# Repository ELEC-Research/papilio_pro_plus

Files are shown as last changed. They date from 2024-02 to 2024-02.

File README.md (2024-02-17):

# Papilio Pro Plus

This is a KICAD implementation of the Papilio Pro including production files for JLCPCB.  The Papilio pro is no longer in production so you can use this to order one for yourself.

There are some changes:
* Built-in USB-C JTAG port

## Author

Phill Brown is the primary author. 

## Licence

This work is licenced under a creative commons licence, rather like the original papilio pro.

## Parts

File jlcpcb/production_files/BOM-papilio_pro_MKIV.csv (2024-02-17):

Comment | Designator | Footprint | LCSC
4k7 | R12 | R_0402_1005Metric | C105870
600 ohm | FB1 | L_0805_2012Metric | C111240
6K8 1% | R3 | R_0603_1608Metric | C114632
10k | R11 | R_0402_1005Metric | C11616
1K8 | R5 | R_0402_1005Metric | C137909
.1uF | C1,C10,C11,C12,C13,C14,C15,C16,C17,C18,C19,C2,C20,C21,C22,C23,C24,C26,C27,C28,C3,C33,C34,C36,C39,C4,C41,C42,C43,C44,C46,C47,C48,C5,C6,C7,C8,C9 | C_0402_1005Metric | C1525
27p | C37,C40 | C_0402_1005Metric | C1557
10u/10V | C25,C29,C30,C31,C32 | C_0805_2012Metric | C15850
USB_C_Receptacle_USB2.0 | J2 | USB_C_Receptacle_HRO_TYPE-C-31-M-12 | C165948
3.3 | C35,C38,C45 | C_0805_2012Metric | C1779
SD103AWS | D3 | D_SOD-323 | C191023
REBOOT | SW1 | SW_SPST_PTS645 | C221872
1.5K 1% | R1,R2,R4 | R_0603_1608Metric | C22843
390 | R6 | R_0402_1005Metric | C25109
470 | R14,R15,R16 | R_0402_1005Metric | C25117
47K | R7 | R_0402_1005Metric | C25563
10k | R17 | R_0402_1005Metric | C25744
12k | R13 | R_0402_1005Metric | C25752
2.2k | R10 | R_0805_2012Metric | C25879
5.1k | R8,R9 | R_0402_1005Metric | C25905
XC6SLX9-TQG144 | U3 | LQFP-144_20x20mm_P0.5mm | C27408
FT2232HL | U7 | LQFP-64_10x10mm_P0.5mm | C27882
3.2X2.5 32MHz Osc | X1 | Oscillator_SMD_Abracon_ASE-4Pin_3.2x2.5mm | C2901581
MT48LC16M16A2P | U5 | TSOP-II-54_22.2x10.16mm_P0.8mm | C41881
93LCxxB | U6 | SO-8_3.9x4.9mm_P1.27mm | C6164
LTC3419MS | U2 | MSOP-10_3x3mm_P0.5mm | C684754
3.3uH | L1,L2 | L_Taiyo-Yuden_MD-5050 | C703751
PWR | D1,D2 | LED_0603_1608Metric | C72043
25CSM04xxSN | U4 | SOIC-8W_5.3x5.3mm_P1.27mm | C82344
~PWREN | D4,D5,D6 | LED_0805_2012Metric | C84256
12MHz | Y1 | Crystal_SMD_3225-4Pin_3.2x2.5mm | C9002

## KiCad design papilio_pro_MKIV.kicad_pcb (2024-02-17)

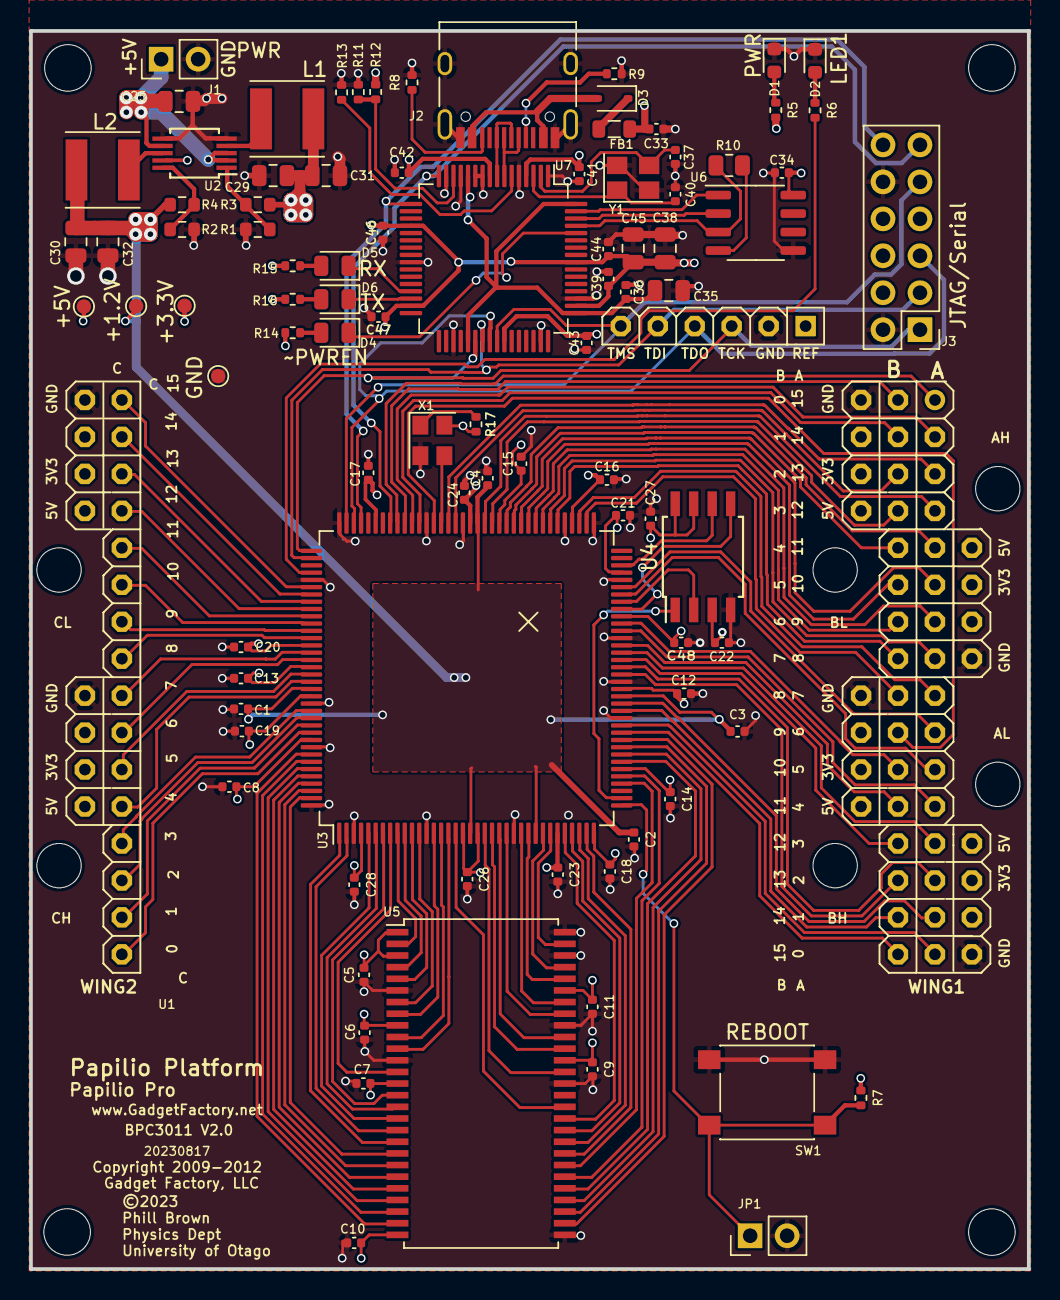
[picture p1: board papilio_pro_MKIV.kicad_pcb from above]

Board: 4 copper layers, 68.6 x 85.1 mm, 96 parts (0 on the bottom side), 132 nets.

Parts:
C1, C2, C3, C4, C5, C6, C7, C8, C9, C10, C11, C12, C13, C14, C15, C16, C17, C18, C19, C20, C21, C22, C23, C24, C26, C27, C28, C48: .1uF; C_0402_1005Metric
C25: 10u/10V; C_0805_2012Metric
C29, C30, C31, C32: 10u/6V3; C_0805_2012Metric
C33, C34, C36, C39, C41, C42, C43, C44, C46, C47: 0.1; C_0402_1005Metric
C35: 3.3; C_0805_2012Metric
C37, C40: 27p; C_0402_1005Metric
C38, C45: 4.7; C_0805_2012Metric
D1: PWR; LED_0603_1608Metric
D2: LED1; LED_0603_1608Metric
D3: SD103AWS; D_SOD-323
D4: ~PWREN; LED_0805_2012Metric
D5: RX; LED_0805_2012Metric
D6: TX; LED_0805_2012Metric
FB1: 600 ohm; L_0805_2012Metric
H1, H2, H3, H4: MountingHole; MountingHole_3.2mm_M3
J1: PWR; PinHeader_1x02_P2.54mm_Vertical
J2: USB_C_Receptacle_USB2.0; USB_C_Receptacle_HRO_TYPE-C-31-M-12
J3: JTAG/Serial; PinHeader_2x06_P2.54mm_Vertical
JP1: JP1E; PinHeader_1x02_P2.54mm_Vertical
L1, L2: 3.3uH; L_Taiyo-Yuden_MD-5050
R1, R2, R4: 1.5K 1%; R_0603_1608Metric
R3: 6K8 1%; R_0603_1608Metric
R5: 1K8; R_0402_1005Metric
R6: 390; R_0402_1005Metric
R7: 47K; R_0402_1005Metric
R8, R9: 5.1k; R_0402_1005Metric
R10: 2.2k; R_0805_2012Metric
R11, R17: 10k; R_0402_1005Metric
R12: 4k7; R_0402_1005Metric
R13: 12k; R_0402_1005Metric
R14, R15, R16: 470; R_0402_1005Metric
SW1: REBOOT; SW_SPST_PTS645
TP1: +3.3V; TestPoint_Pad_D1.0mm
TP2: +1.2V; TestPoint_Pad_D1.0mm
TP3: +5V; TestPoint_Pad_D1.0mm
TP4: GND; TestPoint_Pad_D1.0mm
U1: Papilio Pro; COCOON_48BIT
U2: LTC3419MS; MSOP-10_3x3mm_P0.5mm
U3: XC6SLX9-TQG144; LQFP-144_20x20mm_P0.5mm
U4: 25CSM04xxSN; SOIC-8W_5.3x5.3mm_P1.27mm
U5: MT48LC16M16A2P; TSOP-II-54_22.2x10.16mm_P0.8mm
U6: 93LCxxB; SO-8_3.9x4.9mm_P1.27mm
U7: FT2232HL; LQFP-64_10x10mm_P0.5mm
X1: 3.2X2.5 32MHz Osc; Oscillator_SMD_Abracon_ASE-4Pin_3.2x2.5mm
Y1: 12MHz; Crystal_SMD_3225-4Pin_3.2x2.5mm

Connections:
+1V2: C1.1, C2.1, C3.1, C4.1, C30.1, C32.1, L2.2, R4.2, TP2.1, U3.19 (VCCINT), U3.28 (VCCINT), U3.52 (VCCINT), U3.89 (VCCINT), U3.128 (VCCINT)
+1V8: C35.1, C36.1, U7.12 (VCORE), U7.37 (VCORE), U7.49 (VREGOUT), U7.64 (VCORE)
+3.3V: C5.1, C6.1, C7.1, C8.1, C9.1, C10.1, C11.1, C12.1, C13.1, C14.1, C15.1, C16.1, C17.1, C18.1, C19.1, C20.1, C21.1, C22.1, C23.1, C24.1, C26.1, C27.1, C28.1, C29.1, C31.1, C34.1, C38.1, C39.1, C41.1, C42.1, C43.1, C44.1, C45.1, C46.1, C47.1, C48.1, J3.6, L1.2, R3.2, R7.1, R14.1, R15.1, R16.1, R17.1, TP1.1, U1.3 (3V3), U1.13 (3V3), U1.23 (3V3), U1.33 (3V3), U1.43 (3V3), U1.53 (3V3), U1.J1 (JTAG_REF), U2.9 (RUN2), U3.4 (VCCO_3), U3.18 (VCCO_3), U3.20 (VCCAUX), U3.31 (VCCO_3), U3.36 (VCCAUX), U3.42 (VCCO_2), U3.53 (VCCAUX), U3.63 (VCCO_2), U3.69 (IO_L1N_M0_CMPMISO_2), U3.76 (VCCO_1), U3.86 (VCCO_1), U3.90 (VCCAUX), U3.103 (VCCO_1), U3.122 (VCCO_0), U3.125 (VCCO_0), U3.129 (VCCAUX), U3.135 (VCCO_0), U4.3 (~WP), U4.7 (~HOLD), U4.8 (V_{CC}), U5.1 (VDD), U5.3 (VDDQ), U5.9 (VDDQ), U5.14 (VDD), U5.27 (VDD), U5.43 (VDDQ), U5.49 (VDDQ), U6.8 (VCC), U7.4 (VPHY), U7.9 (VPLL), U7.20 (VCCIO), U7.31 (VCCIO), U7.42 (VCCIO), U7.50 (VREGIN), U7.56 (VCCIO), X1.4 (Vdd)
+5V: C25.1, C33.1, FB1.1, J1.1, R5.2, R12.1, TP3.1, U1.4 (Vin), U1.14 (Vin), U1.24 (Vin), U1.34 (Vin), U1.44 (Vin), U1.54 (Vin), U2.2 (RUN1), U2.3 (MODE), U2.7 (VIN)
/Connectors/OSC_IN: U3.94 (IO_L40N_GCLK10_1), X1.3 (OUT)
/Connectors/W1_A1: U1.A0, U3.48 (IO_L48P_D7_2)
/Connectors/W1_A2: U1.A1, U3.51 (IO_L31P_GCLK31_D14_2)
/Connectors/W1_A3: U1.A2, U3.56 (IO_L30P_GCLK1_D13_2)
/Connectors/W1_A4: U1.A3, U3.58 (IO_L14P_D11_2)
/Connectors/W1_A5: U1.A4, U3.61 (IO_L12N_D2_MISO3_2)
/Connectors/W1_A6: U1.A5, U3.66 (IO_L2N_CMPMOSI_2)
/Connectors/W1_A7: U1.A6, U3.67 (IO_L2P_CMPCLK_2)
/Connectors/W1_A8: U1.A7, U3.75 (IO_L74P_AWAKE_1)
/Connectors/W1_A9: U1.A8, U3.79 (IO_L47P_1)
/Connectors/W1_A10: U1.A9, U3.81 (IO_L46P_1)
/Connectors/W1_A11: U1.A10, U3.83 (IO_L45P_1)
/Connectors/W1_A12: U1.A11, U3.85 (IO_L43P_GCLK5_1)
/Connectors/W1_A13: U1.A12, U3.88 (IO_L42P_GCLK7_1)
/Connectors/W1_A14: U1.A13, U3.93 (IO_L41P_GCLK9_IRDY1_1)
/Connectors/W1_A15: U1.A14, U3.98 (IO_L34P_1)
/Connectors/W1_A16: U1.A15, U3.100 (IO_L33P_1)
/Connectors/W1_B1: U1.B0, U3.99 (IO_L33N_1)
/Connectors/W1_B2: U1.B1, U3.97 (IO_L34N_1)
/Connectors/W1_B3: U1.B2, U3.92 (IO_L41N_GCLK8_1)
/Connectors/W1_B4: U1.B3, U3.87 (IO_L42N_GCLK6_TRDY1_1)
/Connectors/W1_B5: U1.B4, U3.84 (IO_L43N_GCLK4_1)
/Connectors/W1_B6: U1.B5, U3.82 (IO_L45N_1)
/Connectors/W1_B7: U1.B6, U3.80 (IO_L46N_1)
/Connectors/W1_B8: U1.B7, U3.78 (IO_L47N_1)
/Connectors/W1_B9: U1.B8, U3.74 (IO_L74N_DOUT_BUSY_1)
/Connectors/W1_B10: U1.B9, U3.95 (IO_L40P_GCLK11_1)
/Connectors/W1_B11: U1.B10, U3.62 (IO_L12P_D1_MISO2_2)
/Connectors/W1_B12: U1.B11, U3.59 (IO_L13N_D10_2)
/Connectors/W1_B13: U1.B12, U3.57 (IO_L14N_D12_2)
/Connectors/W1_B14: U1.B13, U3.55 (IO_L30N_GCLK0_USERCCLK_2)
/Connectors/W1_B15: U1.B14, U3.50 (IO_L31N_GCLK30_D15_2)
/Connectors/W1_B16: U1.B15, U3.47 (IO_L48N_RDWR_B_VREF_2)
/Connectors/W2_A1: U1.C15, U3.114 (IO_L65N_SCP2_0)
/Connectors/W2_A2: U1.C14, U3.115 (IO_L65P_SCP3_0)
/Connectors/W2_A3: U1.C13, U3.116 (IO_L64N_SCP4_0)
/Connectors/W2_A4: U1.C12, U3.117 (IO_L64P_SCP5_0)
/Connectors/W2_A5: U1.C11, U3.118 (IO_L63N_SCP6_0)
/Connectors/W2_A6: U1.C10, U3.119 (IO_L63P_SCP7_0)
/Connectors/W2_A7: U1.C9, U3.120 (IO_L62N_VREF_0)
/Connectors/W2_A8: U1.C8, U3.121 (IO_L62P_0)
/Connectors/W2_A9: U1.C7, U3.123 (IO_L37N_GCLK12_0)
/Connectors/W2_A10: U1.C6, U3.124 (IO_L37P_GCLK13_0)
/Connectors/W2_A11: U1.C5, U3.126 (IO_L36N_GCLK14_0)
/Connectors/W2_A12: U1.C4, U3.127 (IO_L36P_GCLK15_0)
/Connectors/W2_A13: U1.C3, U3.131 (IO_L35N_GCLK16_0)
/Connectors/W2_A14: U1.C2, U3.132 (IO_L35P_GCLK17_0)
/Connectors/W2_A15: U1.C1, U3.133 (IO_L34N_GCLK18_0)
/Connectors/W2_A16: U1.C0, U3.134 (IO_L34P_GCLK19_0)
/FPGA/A0: U3.140 (IO_L3P_0), U5.23 (A0)
/FPGA/A1: U3.139 (IO_L3N_0), U5.24 (A1)
/FPGA/A2: U3.138 (IO_L4P_0), U5.25 (A2)
/FPGA/A3: U3.137 (IO_L4N_0), U5.26 (A3)
/FPGA/A4: U3.46 (IO_L49P_D3_2), U5.29 (A4)
/FPGA/A5: U3.45 (IO_L49N_D4_2), U5.30 (A5)
/FPGA/A6: U3.44 (IO_L62P_D5_2), U5.31 (A6)
/FPGA/A7: U3.43 (IO_L62N_D6_2), U5.32 (A7)
/FPGA/A8: U3.41 (IO_L64P_D8_2), U5.33 (A8)
/FPGA/A9: U3.40 (IO_L64N_D9_2), U5.34 (A9)
/FPGA/A10: U3.141 (IO_L2N_0), U5.22 (A10)
/FPGA/A11: U3.35 (IO_L1P_3), U5.35 (A11)
/FPGA/A12: U3.34 (IO_L1N_VREF_3), U5.36 (A12)
/FPGA/BA0: U3.143 (IO_L1N_VREF_0), U5.20 (BA0)
/FPGA/BA1: U3.142 (IO_L2P_0), U5.21 (BA1)
/FPGA/CKE: U3.33 (IO_L2P_3), U5.37 (CKE)
/FPGA/CLK: U3.32 (IO_L2N_3), U5.38 (CLK)
/FPGA/CS: U3.1 (IO_L83N_VREF_3), U5.19 (~CS)
/FPGA/DQ0: U3.9 (IO_L50N_3), U5.2 (DQ0)
/FPGA/DQ1: U3.10 (IO_L50P_3), U5.4 (DQ1)
/FPGA/DQ2: U3.11 (IO_L49N_3), U5.5 (DQ2)
/FPGA/DQ3: U3.12 (IO_L49P_3), U5.7 (DQ3)
/FPGA/DQ4: U3.14 (IO_L44N_GCLK20_3), U5.8 (DQ4)
/FPGA/DQ5: U3.15 (IO_L44P_GCLK21_3), U5.10 (DQ5)
/FPGA/DQ6: U3.16 (IO_L43N_GCLK22_IRDY2_3), U5.11 (DQ6)
/FPGA/DQ7: U3.8 (IO_L51P_3), U5.13 (DQ7)
/FPGA/DQ8: U3.21 (IO_L42N_GCLK24_3), U5.42 (DQ8)
/FPGA/DQ9: U3.22 (IO_L42P_GCLK25_TRDY2_3), U5.44 (DQ9)
/FPGA/DQ10: U3.23 (IO_L41N_GCLK26_3), U5.45 (DQ10)
/FPGA/DQ11: U3.24 (IO_L41P_GCLK27_3), U5.47 (DQ11)
/FPGA/DQ12: U3.26 (IO_L37N_3), U5.48 (DQ12)
/FPGA/DQ13: U3.27 (IO_L37P_3), U5.50 (DQ13)
/FPGA/DQ14: U3.29 (IO_L36N_3), U5.51 (DQ14)
/FPGA/DQ15: U3.30 (IO_L36P_3), U5.53 (DQ15)
/FPGA/DQMH: U3.17 (IO_L43P_GCLK23_3), U5.39 (DQMH)
/FPGA/DQML: U3.7 (IO_L51N_3), U5.15 (DQML)
/FPGA/FLASH_CS: U3.38 (IO_L65N_CSO_B_2), U4.1 (~CS)
/FPGA/FLASH_SCK: U3.70 (IO_L1P_CCLK_2), U4.6 (SCK)
/FPGA/FLASH_SI: U3.64 (IO_L3N_MOSI_CSI_B_MISO0_2), U4.5 (SI)
/FPGA/FLASH_SO: U3.65 (IO_L3P_D0_DIN_MISO_MISO1_2), U4.2 (SO)
/FPGA/FPGA-C/REBOOT: JP1.1, R7.2, SW1.1, U3.37 (PROGRAM_B_2)
/FPGA/~CAS: U3.5 (IO_L52N_3), U5.17 (~CAS)
/FPGA/~RAS: U3.2 (IO_L83P_3), U5.18 (~RAS)
/FPGA/~WE: U3.6 (IO_L52P_3), U5.16 (~WE)
/USB JTAG/RXD2: J3.12, U3.105 (IO_L1P_1), U7.17 (ADBUS1)
/USB JTAG/TCK: J3.1, U1.J3 (JTAG_TCK), U3.109 (TCK), U7.38 (BDBUS0)
/USB JTAG/TDI: J3.3, U1.J5 (JTAG_TDI), U3.110 (TDI), U7.39 (BDBUS1)
/USB JTAG/TDO: J3.5, U1.J4 (JTAG_TDO), U3.106 (TDO), U7.40 (BDBUS2)
/USB JTAG/TMS: J3.9, U1.J6 (JTAG_TMS), U3.107 (TMS), U7.41 (BDBUS3)
/USB JTAG/TXD2: J3.11, U3.101 (IO_L32N_1), U7.16 (ADBUS0)
GND: C1.2, C2.2, C3.2, C4.2, C5.2, C6.2, C7.2, C8.2, C9.2, C10.2, C11.2, C12.2, C13.2, C14.2, C15.2, C16.2, C17.2, C18.2, C19.2, C20.2, C21.2, C22.2, C23.2, C24.2, C25.2, C26.2, C27.2, C28.2, C29.2, C30.2, C31.2, C32.2, C33.2, C34.2, C35.2, C36.2, C37.2, C38.2, C39.2, C40.2, C41.2, C42.2, C43.2, C44.2, C45.2, C46.2, C47.2, C48.2, D1.1 (K), D2.1 (K), J1.2, J2.A1 (GND), J2.A12 (GND), J2.B1 (GND), J2.B12 (GND), J2.S1 (SHIELD), J3.2, J3.10, JP1.2, R1.1, R2.1, R8.2, R9.2, R11.2, R13.2, SW1.2, TP4.1, U1.1 (GND), U1.11 (GND), U1.21 (GND), U1.31 (GND), U1.41 (GND), U1.51 (GND), U1.J2 (JTAG_GND), U2.5 (GND), U2.6 (GND), U3.3 (GND), U3.13 (GND), U3.25 (GND), U3.49 (GND), U3.54 (GND), U3.60 (IO_L13P_M1_2), U3.68 (GND), U3.73 (SUSPEND), U3.77 (GND), U3.91 (GND), U3.96 (GND), U3.108 (GND), U3.113 (GND), U3.130 (GND), U3.136 (GND), U3.144 (IO_L1P_HSWAPEN_0), U4.4 (V_{SS}), U5.6 (VSSQ), U5.12 (VSSQ), U5.28 (VSS), U5.41 (VSS), U5.46 (VSSQ), U5.52 (VSSQ), U5.54 (VSS), U6.5 (GND), U7.1 (GND), U7.5 (GND), U7.10 (AGND), U7.11 (GND), U7.13 (TEST), U7.15 (GND), U7.25 (GND), U7.35 (GND), U7.47 (GND), U7.51 (GND), X1.2 (GND), Y1.2, Y1.4
unnamed: D1.2 (A), R5.1
unnamed: D2.2 (A), R6.1
unnamed: D3.2 (A), J2.A4 (VBUS), J2.A9 (VBUS), J2.B4 (VBUS), J2.B9 (VBUS)
unnamed: D3.1 (K), FB1.2
unnamed: D4.2 (A), R14.2
unnamed: D4.1 (K), U7.60 (~PWREN)
unnamed: D5.2 (A), R15.2
unnamed: D5.1 (K), U7.29 (ACBUS3)
unnamed: D6.2 (A), R16.2
unnamed: D6.1 (K), U7.30 (ACBUS4)
unnamed: J2.A5 (CC1), R9.1
unnamed: J2.B5 (CC2), R8.1
unnamed: L1.1, U2.4 (SW1)
unnamed: L2.1, U2.8 (SW2)
unnamed: R1.2, R3.1, U2.1 (VFB1)
unnamed: R2.2, R4.1, U2.10 (VFB2)
unnamed: R6.2, U3.112 (IO_L66P_SCP1_0)
unnamed: U6.1 (CS), U7.63 (EECS)
unnamed: R10.1, U6.3 (DI), U7.61 (EEDATA)
unnamed: R10.2, U6.4 (DO)
unnamed: U6.2 (SCLK), U7.62 (EECLK)
unnamed: J2.A7 (D-), J2.B7 (D-), U7.7 (DM)
unnamed: J2.A6 (D+), J2.B6 (D+), U7.8 (DP)
unnamed: C37.1, U7.2 (OSCI), Y1.3
unnamed: C40.1, U7.3 (OSCO), Y1.1
unnamed: R13.1, U7.6 (REF)
unnamed: R11.1, R12.2, U7.14 (~RESET)
unnamed: R17.2, X1.1 (EN)

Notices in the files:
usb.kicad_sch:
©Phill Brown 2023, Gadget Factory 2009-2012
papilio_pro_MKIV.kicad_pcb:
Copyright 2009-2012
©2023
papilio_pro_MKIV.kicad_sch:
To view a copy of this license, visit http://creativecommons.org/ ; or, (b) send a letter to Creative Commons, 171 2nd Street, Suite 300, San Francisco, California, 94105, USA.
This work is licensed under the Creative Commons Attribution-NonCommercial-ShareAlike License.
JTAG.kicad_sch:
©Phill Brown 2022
